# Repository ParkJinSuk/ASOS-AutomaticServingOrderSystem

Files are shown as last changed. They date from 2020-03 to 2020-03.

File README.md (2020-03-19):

# Project Name 

ASOS
Automatic Serving & Order System 

# Project period & team members

2020.02.21 ~ 2020.03.21 (4주) 
시립대 박진석, 서재원, 송태헌

# 요약 

본 프로젝트는 식당에서 사용할 수 있는 자동으로 서빙을 해주는 무인 서빙 로봇, 주문을 해주는 어플리케이션과 주문을 확인하고 서빙 명령이 가능한 웹페이지 제작을 한다. 서빙 로봇은 Wi-Fi와 연결되었기 때문에 공유기가 설치된 환경이면 어디서든 환경이 가능하고, 주문한 음식은 서버에 저장되기 때문에 완벽한 IoT를 구현하였다.   

# 개발 배경 

현대사회에서 생산성과 효율을 위해서 많은 분야에서 무인/자동화가 이루어지고 있다. 이러한 추세에 따라 매장에 무인 주문 결제기인 ‘키오스크’가 설치되고 있고, 일부 매장은 어플로 주문을 하는 시스템을 도입했다. 따라서 위의 주문 시스템에 자동으로 서빙을 로봇을 융합함으로 IoT를 이용한 무인 서비스 제공을 목표로 한다. 

# 프로젝트 목적 및 기대효과 

이 프로젝트의 목적은 주문/서빙 시스템의 자동화이다. 병렬적으로 주문을 할 수 있는 무인 주문서비스와 무인 서빙 서비스를 만드는 것이 목표이다. 무인 서빙 서비스가 있기 때문에 서빙에 필요한 인건비가 줄어들어 경제적이고 효율적이다. 무인 주문 서비스를 통해서 순간적으로 사람이 집중이 되더라도 주문하는데 기다릴 필요가 없게 된다. 또한, 주방에서 출력된 종이 영수증을 보통 주문의 순서를 정하는데, 이 프로젝트를 통해서 종이 영수증대신 태블릿 PC와 같은 전자기기로 대체할 수 있을 것이다. 이에 따라 주방에서 낭비되는 종이의 양을 줄여서 환경보호면에서도 효과가 있다. 또한, 보드는 Arduino UNO만을 사용하고 성능을 대부분 사용하여 개발을 했기 때문에 실제 제품으로 만들 시 제품 비용 절감이 매우 절감될 것이다.  

# MySQL 명령어 모음

Column 이름 변경
```
ALTER TABLE `project`.`orderDB` 
CHANGE COLUMN `order` `_order` INT(11) NOT NULL AUTO_INCREMENT ,
CHANGE COLUMN `table` `_table` INT(11) NOT NULL ;
```

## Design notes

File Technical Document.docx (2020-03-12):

# 2020 ICT 융합 프로젝트 공모전

# 1. 프로젝트 소개

## 1.1 프로젝트 명

Linetracer를 활용한 Restaurants Serving Robot

## 1.2 프로젝트 기간

2020.02.21 ~ 2020.03.21 (4주)

## 1.3 프로젝트 팀원

서울시립대학교 기계정보공학과 갓진석

서울시립대학교 기계정보공학과 서재원

서울시립대학교 기계정보공학과 송태헌

# 2. 프로젝트 개요

## 2.1 요약

라인트레이서 센서를 사용해서 식당에서 사람을 대신해서 음식을 서빙 해주는 로봇과 식당 테이블에서 QR 코드를 통해서 주문을 할 수 있는 무인 주문&서빙 시스템을 제작한다. 식당 이용객은 테이블 QR 코드를 찍음으로써 간단하게 주문을 하고 주문을 받는 주방에서는 로봇 위에 음식을 올려놓으면 자동으로 주문한 테이블로 배달이 되도록 한다.

## 2.2 개발 배경

현대사회에서 생산성과 효율을 위해서 많은 분야에서 무인화/자동화가 이루어지고 있다. 이러한 추세에 따라 매장에 무인 주문 결제기인 ‘키오스크’가 설치되고 있고, 일부 매장은 어플로 주문을 하는 시스템을 도입했다. 본 프로젝트에서는 위의 주문 시스템에 자동으로 서빙을 로봇을 융합함으로 IoT를 이용한 무인 서비스 제공을 목표로 한다.

## 2.3 프로젝트 목적 및 기대효과

이 프로젝트의 목적은 주문&서빙 시스템의 자동화 및 디지털화이다. 병렬적으로 주문을 할 수 있는 무인 주문서비스와 무인 서빙 서비스를 만드는 것이 목표이다. 무인 서빙 서비스가 있기 때문에 서빙에 필요한 인건비가 줄어들어 경제적이고 효율적이다. 무인 주문 서비스를 통해서 순간적으로 사람이 집중이 되더라도 주문하는데 기다릴 필요가 없게 된다. 또한, 주방에서 출력된 종이 영수증을 보통 주문의 순서를 정하는데, 이 프로젝트를 통해서 종이 영수증대신 태블릿 PC와 같은 전자기기로 대체할 수 있을 것이다. 이에 따라 주방에서 낭비되는 종이의 양을 줄여서 환경보호면에서도 효과가 있다.

## 2.4 개발 목표

많은 사람들이 집중되더라도 한꺼번에 처리가 가능한 무인 병렬 주문 서비스와 주방에서 서빙할 테이블의 번호를 지정해준다면 자동으로 서빙을 해주는 서비스 구현이 목표이다.

## 2.5 세부 개발 내용

네이버 클라우드에 비용을 지불해서 구축한 서버에 APM(Apache2, PHP, MySQL)을 설치하고, 웹 페이지와 안드로이드 어플을 제작하여 주문한 데이터가 DB인 MySQL에 저장되도록 한다. 관리자는 관리자용 웹페이지를 통해서 MySQL에 저장된 데이터를 확인해서 들어온 주문을 확인할 수 있다. 서빙을 원하는 테이블을 웹 페이지에 입력하면 마찬가지로 MySQL에 저장이 된다. 아두이노는 매장에 설치된 Wi-Fi와 연결된 상태로 구동되고, 일정 간격으로 MySQL을 확인해서 서빙 요청이 왔는지 확인한다. 서빙 명령을 받게 되면 목표 테이블까지 라인트레이싱을 하며 도달하게 된다. 이 때 서빙 하는 음식의 무게에 상관없고, 가속도에 의한 음식의 미끄러짐을 최소화하기 위해서 모터 PID속도 제어를 통해서 운동한다.

# 3. 프로젝트 설명

## 3.1 주요 동작 및 특징

QR코드를 통한 웹페이지 접근 -> 주문이 MySQL에 쌓임

주방에서 웹페이지를 실시간으로 확인이 가능 -> 서빙을 원하는 테이블 번호를 MySQL에 전송

Arduino에서 실시간으로 Wi-Fi를 통한 TCP 통신 -> MySQL에서 테이블 번호를 입력 받음 -> 해당 테이블로 이동

Arduino가 급격하게 움직이면서 관성으로 인한 음식 떨어뜨림, 안전하고 신속하게 이동할 수 있는 최적 속도를 계산해서 구동하도록 하는 모터 PID 제어

## 3.2 전체 시스템 구성

### 3.2.1. Software Architecture

#### 3.2.1.1. Server Flowchart

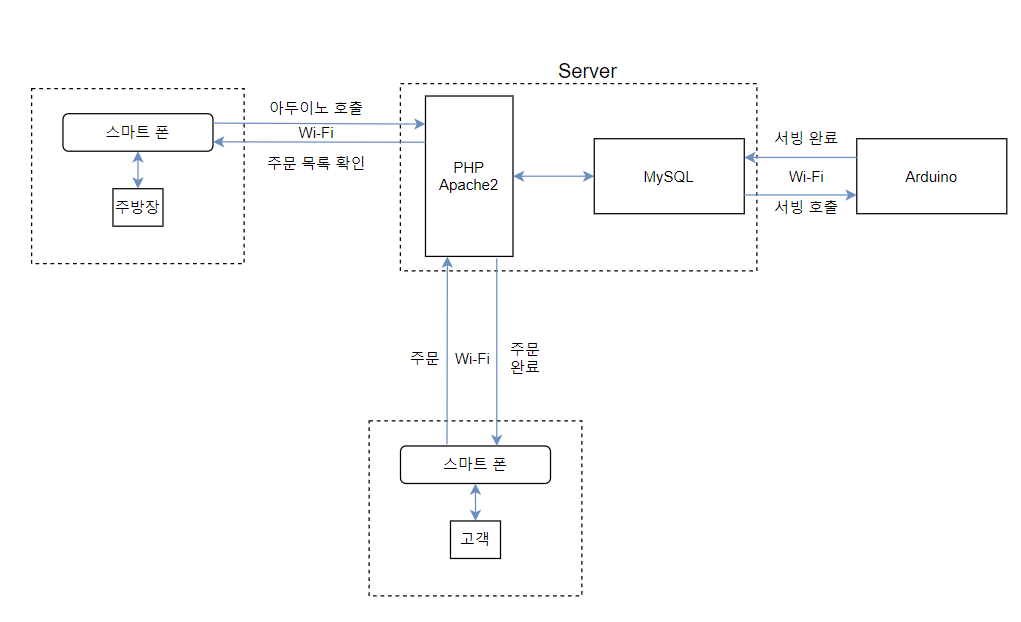
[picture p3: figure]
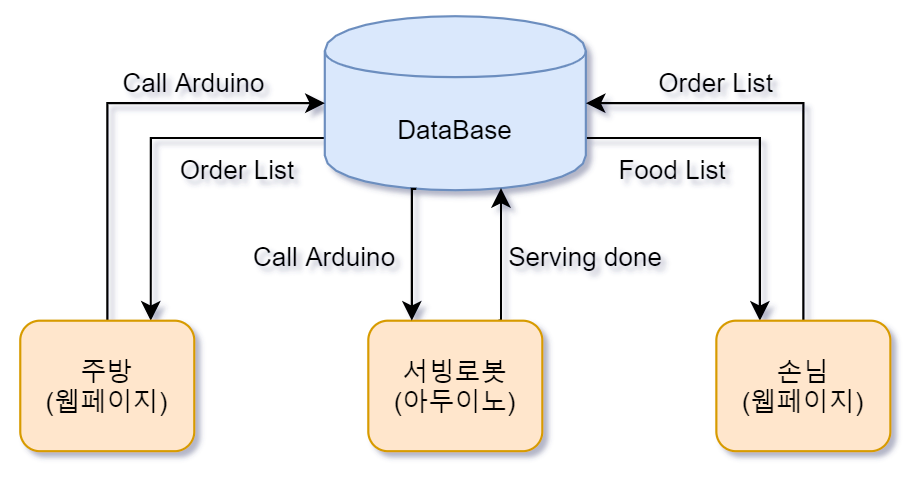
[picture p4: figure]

손님이 주문을 하고 RC카(아두이노)가 서빙을 하기 위한 방법으로 서버를 사용하였다. 손님이 주문을 하면 주문내역이 서버의 데이터베이스에 저장이 되고 주방에서는 서버의 데이터베이스를 확인하여 RC카(아두이노)를 호출한다. RC카(아두이노)에서는 서버의 데이터베이스를 통해서 호출 신호가 왔을 때, 지정된 테이블로 음식을 서빙한다.

3.2.2. Hardware Architecture

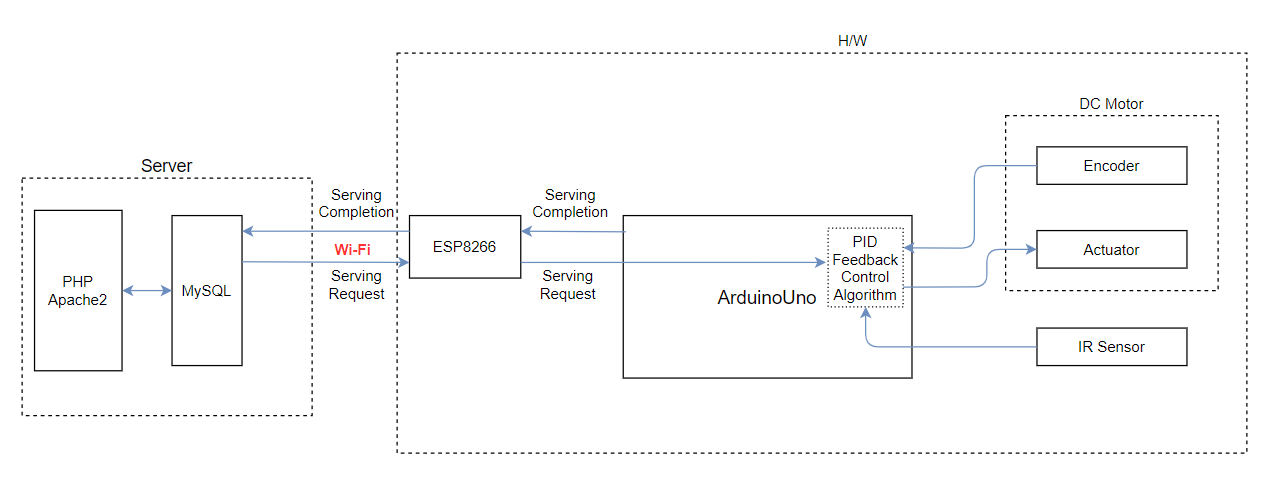
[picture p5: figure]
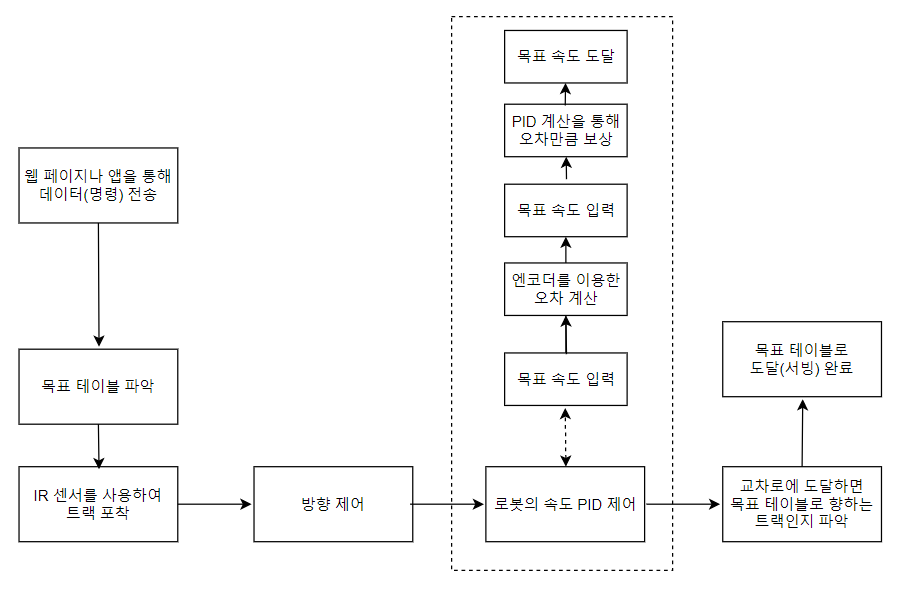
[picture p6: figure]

## 3.3 개발 환경(개발 언어, Tool, 사용 시스템 등)

구분 | | 내용
서버 구축 | 플랫폼 | 네이버 클라우드
| OS | Ubuntu 16.04 (Linux)
| Tool | Apache2/MySQL/PHP
| 개발 언어 | html/PHP/C/C++
H/W | 디바이스 | Arduino Uno/DC Motor W/ Encoder
| 센서 | HS-IR-TRACE-II
| Wi-Fi 통신 | ESP8266
| 개발 언어 | C/C++
| 기타 | MATLAB Simulink를 통한 DC모터의 PID 제어

# 4. 단계별 제작 과정

## 4.1. 서버구축

서버는 네이버 클라우스 서비스를 사용하여 구축하였다. 기본적으로 유료서비스이지만 작은 규모의 서버를 1년동안 무료로 사용할 수 있는 이벤트가 있어서 네이버 서버를 선택하였다. 서버의 사양은 [Micro] 1vCPU, 1GB Mem, 50GB Disk이라 성능은 좋지 않지만 이번 프로젝트에서는 문제가 없다고 판단하였다. 서버의 OS는 Ubuntu 16.04 LTS Server를 설치하였다.

## 4.2 APM 설치

(갓째원 적어줘요~)

## 4.3 MySQL 데이터베이스 구축

Windows에서 MySQL Workbench를 설치하여 좀 더 쉽게 MySQL를 다룰 수 있도록 하였다. orderDB의 테이블 속, 각 데이터들은 다음을 의미한다. _order는 주문순서, time는 주문시간, _table는 주문 테이블 번호, food는 주문한 음식과 수량, serving는 서빙이 완료되었는지 안되었는지, call_arduino는 RC카(아두이노)가 확인하는 데이터로써 값이 1일 경우, RC카(아두이노)가 음식을 서빙한다.

_order열에는 값을 입력하지 않아도 자동으로 값이 1씩 증가하도록 설정하였고, time은 ubuntu서버에 있는 시간을 자동으로 입력 받도록 설정하였다. 아래에 기술할 웹페이지에서 _table, food, call_arduino열을 설정할 수 있도록 연동하였다.

## 4.4 웹 페이지 제작

4.4.1 손님용 웹 페이지

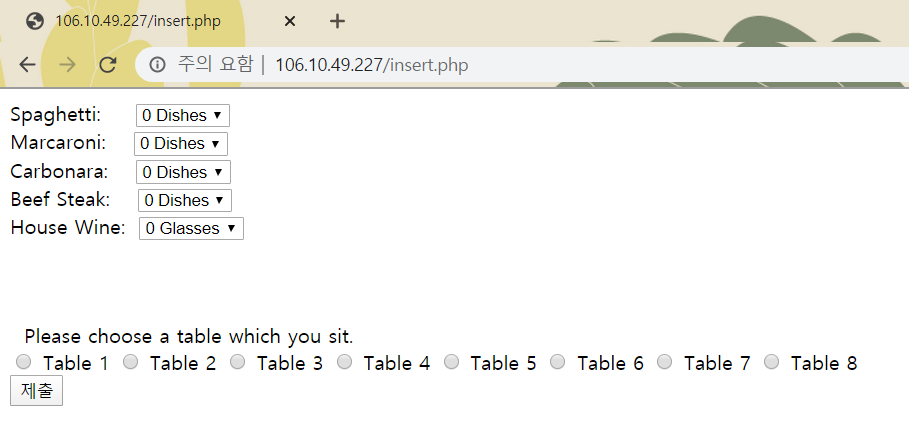
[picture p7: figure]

손님용 웹페이지

구축한 서버를 통해 웹 페이지를 제작했고, 포트 포워딩을 설정하여 외부 IP를 이용하여 접속이 가능하도록 하였다. 현재 제공하고 있는 음식의 목록과 개수를 HTML 리스트박스를 통해서 선택하고, 앉을 테이블 번호를 라디오 버튼을 이용해서 선택할 수 있다. ‘제출’버튼을 누르면 서버의 데이터베이스인 MySQL에 저장이 된다. insert.php에서는 웹 페이지에서 정보를 받아와서 MySQL에 데이터를 입력하는 코드를 구성하였고, dbcon.php에는 MySQL에 접근하는 코드를 구현하였다. 이 웹 페이지를 생성하기 위한 php파일의 코드는 아래와 같다.

insert.php 코드

<?php

error_reporting(E_ALL);

ini_set('display_errors',1);

include('dbcon.php');

if( ($_SERVER['REQUEST_METHOD'] == 'POST') && isset($_POST['submit']))

{

$_table=$_POST['_table'];

$food="Spaghetti: ".$_POST['amount_a']."<br>Macaroni: ".$_POST['amount_b']."<br>Carbonara: ".$_POST['amount_c']."<br>Beef Steak: ".$_POST['amount_d']."<br>House Wine: ".$_POST['amount_e'];

if(!isset($errMSG))

{

try{

$stmt = $con->prepare('INSERT INTO orderDB(_table, food) VALUES(:_table, :food)');

$stmt->bindParam(':_table', $_table);

$stmt->bindParam(':food', $food);

if($stmt->execute())

{

$errMSG = 'We just got your order. Thank you.';

}

else

{

$errMSG = "Unexpected error occured. Please try again.";

}

} catch(PDOException $e) {

die("Database error: " . $e->getMessage());

}

}

}

?>

<html>

<body>

<?php

if (isset($errMSG)) echo $errMSG;

if (isset($successMSG)) echo $successMSG;

?>

<form action="<?php $_PHP_SELF ?>" method="POST">

Spaghetti:&nbsp;&nbsp;&nbsp;&nbsp;

<select name="amount_a">

<option value="0"> 0 Dishes</option>

<option value="1"> 1 Dish</option>

<option value="2"> 2 Dishes</option>

<option value="3"> 3 Dishes</option>

<option value="4"> 4 Dishes</option>

</select>

<br>

Marcaroni:&nbsp;&nbsp;&nbsp;

<select name="amount_b">

<option value="0"> 0 Dishes</option>

<option value="1"> 1 Dish</option>

<option value="2"> 2 Dishes</option>

<option value="3"> 3 Dishes</option>

<option value="4"> 4 Dishes</option>

</select>

<br>

Carbonara:&nbsp;&nbsp;&nbsp;

<select name="amount_c">

<option value="0"> 0 Dishes</option>

<option value="1"> 1 Dish</option>

<option value="2"> 2 Dishes</option>

<option value="3"> 3 Dishes</option>

<option value="4"> 4 Dishes</option>

</select>

<br>

Beef Steak:&nbsp;&nbsp;&nbsp;

<select name="amount_d">

<option value="0"> 0 Dishes</option>

<option value="1"> 1 Dish</option>

<option value="2"> 2 Dishes</option>

<option value="3"> 3 Dishes</option>

<option value="4"> 4 Dishes</option>

</select>

<br>

House Wine:&nbsp;

<select name="amount_e">

<option value="0"> 0 Glasses</option>

<option value="1"> 1 Glass</option>

<option value="2"> 2 Glasses</option>

<option value="3"> 3 Glasses</option>

<option value="4"> 4 Glasses</option>

</select>

<br>

<form action="<?php $_PHP_SELF ?>" method="POST">

<br><br><br> &nbsp; Please choose a table which you sit. <br>

<input type = "radio" name = "_table" value = "1" /> Table 1

<input type = "radio" name = "_table" value = "2" /> Table 2

<input type = "radio" name = "_table" value = "3" /> Table 3

<input type = "radio" name = "_table" value = "4" /> Table 4

<input type = "radio" name = "_table" value = "5" /> Table 5

<input type = "radio" name = "_table" value = "6" /> Table 6

<input type = "radio" name = "_table" value = "7" /> Table 7

<input type = "radio" name = "_table" value = "8" /> Table 8 <br>

<input type = "submit" name = "submit" />

</form>

</body>

</html>

dbcon.php 코드

<?php

$host = 'localhost';

$username = '#########'; # MySQL 계정 아이디

$password = '#########'; # MySQL 계정 패스워드

$dbname = 'project'; # DATABASE 이름

$options = array(PDO::MYSQL_ATTR_INIT_COMMAND => 'SET NAMES utf8');

try {

$con = new PDO("mysql:host={$host};dbname={$dbname};charset=utf8",$username, $password);

} catch(PDOException $e) {

die("Failed to connect to the database: " . $e->getMessage());

}

$con->setAttribute(PDO::ATTR_ERRMODE, PDO::ERRMODE_EXCEPTION);

$con->setAttribute(PDO::ATTR_DEFAULT_FETCH_MODE, PDO::FETCH_ASSOC);

if(function_exists('get_magic_quotes_gpc') && get_magic_quotes_gpc()) {

function undo_magic_quotes_gpc(&$array) {

foreach($array as &$value) {

if(is_array($value)) {

undo_magic_quotes_gpc($value);

}

else {

$value = stripslashes($value);

}

}

}

undo_magic_quotes_gpc($_POST);

undo_magic_quotes_gpc($_GET);

undo_magic_quotes_gpc($_COOKIE);

}

header('Content-Type: text/html; charset=utf-8');

#session_start();

?>

4.4.2 관리자용 웹 페이지

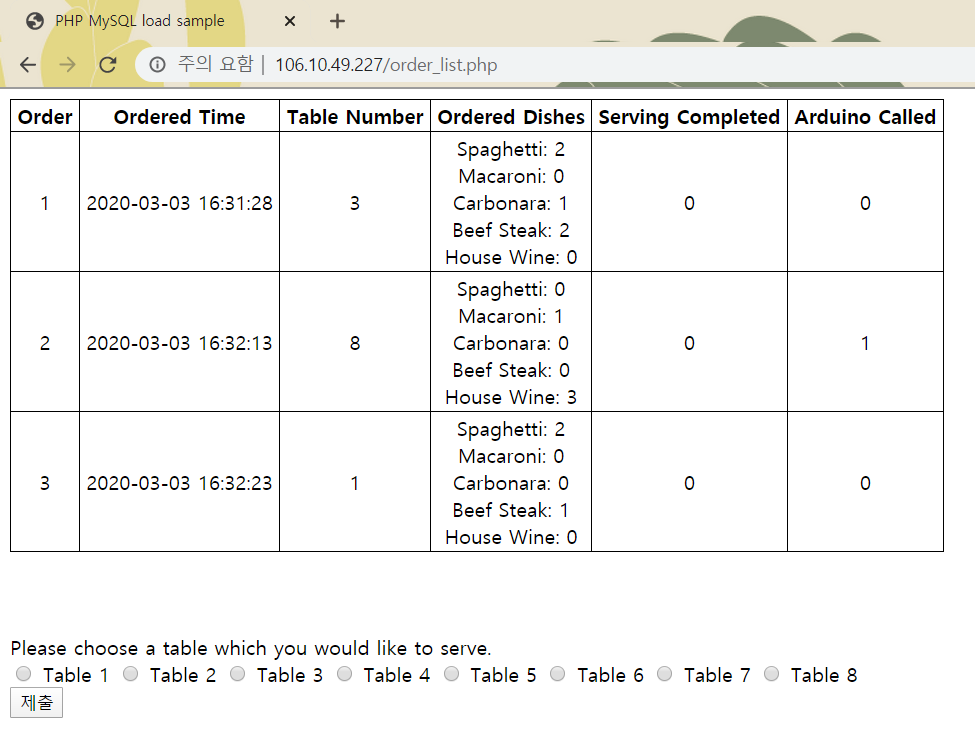
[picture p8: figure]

손님용 웹페이지에서 입력한 MySQL 정보를 읽어와서 표로 표현해주는 기능을 한다. 요리가 완료되면 아래에 있는 테이블 번호를 입력하고 ‘제출’버튼을 누르면 Arduino Called열이 1로 바뀌어 아두이노에게 서빙 명령을 내릴 수 있다. 위의 기능을 실행하기 위한 order_list.php의 코드는 아래와 같다.

<CTYPE html>

<html>

<head>

<meta charset="UTF-8" />

<title>PHP MySQL load sample</title>

<style type="text/css">

table {

border: 0;

border-collapse: collapse;

border-spacing: 0;

}

table td, table th {

border: 1px solid;

padding: 2px 5px 2px 5px;

}

.text-center { text-align: center; }

.text-right { text-align: right; }

</style>

</head>

<body>

<?php

/* Load DB */

$conn = mysqli_connect('localhost', '#######', '########', 'project'); #MySQL 아이디, 패스워드 입력

if ( !$conn ) die('DB Error');

/* Set to UTF-8 Encoding */

mysqli_query($conn, 'set session character_set_connection=utf8;');

mysqli_query($conn, 'set session character_set_results=utf8;');

mysqli_query($conn, 'set session character_set_client=utf8;');

/* Load data */

$query = 'SELECT * FROM orderDB';

$result = mysqli_query($conn, $query);

echo '<table class="text-center"><tr>' .

'<th>Order</th><th>Ordered Time</th><th>Table Number</th><th>Ordered Dishes</th><th>Serving Completed</th><th>Arduino Called</th>' .

'</tr>';

while( $row = mysqli_fetch_array($result) ) {

echo '<tr><td>' . $row['_order'] . '</td>' .

'<td>' . $row['time'] . '</td>' .

'<td>' . $row['_table']. '</td>' .

'<td>' . $row['food'] . '</td>' .

'<td>' . $row['serving']. '</td>' .

// '<td class="text-right">' .

'<td>' . $row['call_arduino'] . '</td></tr>';

}

echo '</table>';

//mysqli_close($conn);

?>

<form action="<?php $_PHP_SELF ?>" method="POST">

<br><br><br> Please choose a table which you would like to serve. <br>

<input type = "radio" name = "table_num" value = "1" /> Table 1

<input type = "radio" name = "table_num" value = "2" /> Table 2

<input type = "radio" name = "table_num" value = "3" /> Table 3

<input type = "radio" name = "table_num" value = "4" /> Table 4

<input type = "radio" name = "table_num" value = "5" /> Table 5

<input type = "radio" name = "table_num" value = "6" /> Table 6

<input type = "radio" name = "table_num" value = "7" /> Table 7

<input type = "radio" name = "table_num" value = "8" /> Table 8 <br>

<input type = "submit" name = "submit" />

</form>

<?php

$insertQuery = "update orderDB set call_arduino = 1 where _table = ".$_POST['table_num'];

mysqli_query($conn, $insertQuery);

?>

</body>

</html>

## 4.5 QR코드 생성

웹사이트 https://ko.qr-code-generator.com/ 에서 URL를 QR코드로 바꿔주는 서비스를 통해서 웹페이지 두개(관리자용, 손님용)를 QR코드로 바꾸어 주었다.

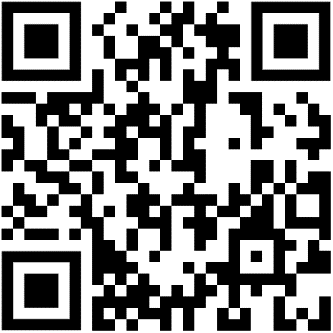
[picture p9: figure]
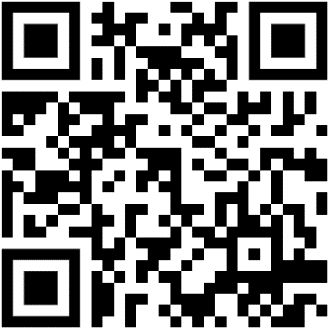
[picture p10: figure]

QR코드(관리자용) | QR코드(손님용)

## 4.6 Arduino에서 Wi-Fi통신을 통한 MySQL 데이터 수신

## 4.7 DC모터의 PID Feedback Control

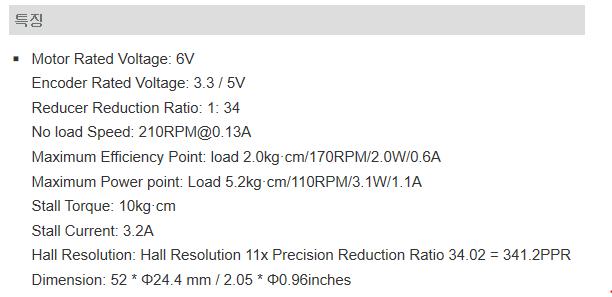
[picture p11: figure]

위의 모터의 Specification을 참고해서 [T:토크(kgf∙cm) V:전압(V), I:전류(A), w:각속도(rad/s), R:저항(Ω)] 아래의 관계식을 세울 수 있다.

T∝ (VI)/w

V=IR

두개의 식을 연립하고 비례상수 k를 도입하면 아래의 식으로 변환이 가능하다.

Tw=k (V^2)/R

Stall Torque는 최대 토크의 값을 의미하고, 이는 최대 전압인 6V와 Stall Current인 3.2A일 때 성립한다. 따라서 옴의 법칙에 의해서

6=3.2R

R=1.875Ω

모터의 저항은 1.875Ω이다.

또한, Maximum Power Point의 값을 Tw=k (V^2)/R 에 대입하면

5.2=k 3.1/11.5192

k=19.3225

비례상수 k값을 수 있다. 위의 식을 정리하면

Tw= V^2 k/R = V^2 19.3225/1.875 =10.3053 V^2

Tw=10.3053 V^2

# 의 식을 구할 수 있다. 아두이노에서 pwm제어로 V를 제어할 수 있기 때문에, V가 각각 1V, 2V, 3V, 4V, 5V, 6V일 때 x축을 각속도, y축을 토크로 그래프를 도사하면 아래와 같다.

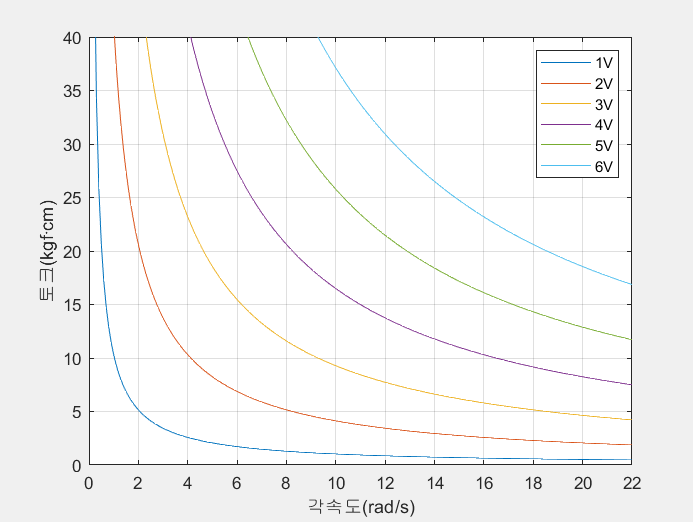
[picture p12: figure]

전압을 가했을 때 각속도와 토크의 값을 정확히 모델링으로부터 알 수 없기 때문에, 엔코더를 이용해서 측정한 각속도 각속도 값은 다음과 같다.

V | rad/s
2 | 4.5524
3 | 4.858997
4 | 7.366162
5 | 23.95988
6 | 24.6999

이 값을 바탕으로 토크 값을 추출하고, Line Fitting을 통해서 전압<->각속도, 전압<->토크의 관계를 알아낼 수 있다.

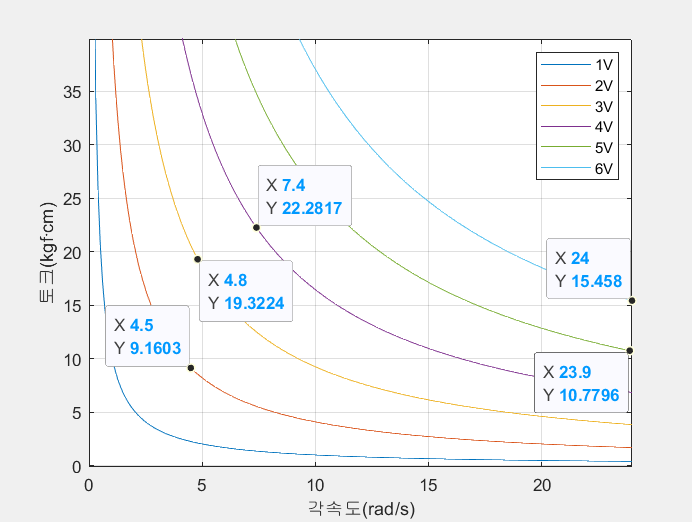
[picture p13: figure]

아마도 위의 데이터는 날려버랴아 할 듯 ㅠㅠㅠㅠㅠㅠ

또한, DC모터의 스펙으로부터 전류에 다른 토크의 값을 아래와 같이 기입할 수 있다.

V | rad/s
2 | 4.5524
3 | 4.858997
4 | 7.366162
5 | 23.95988
6 | 24.6999

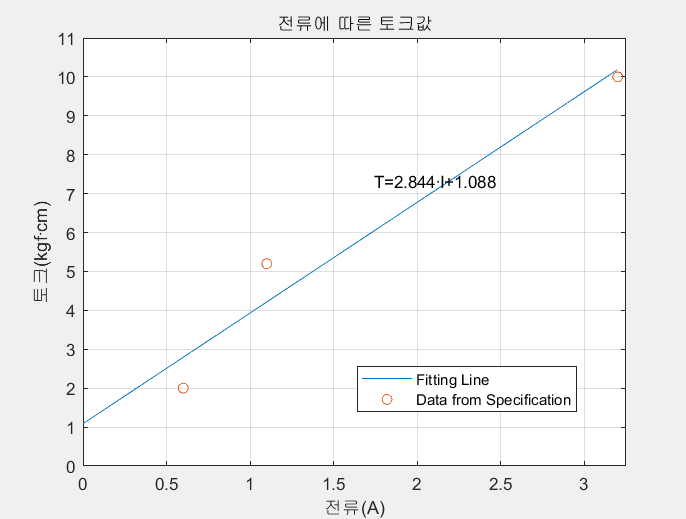
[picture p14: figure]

DC모터, 아두이노 차체 시스템에서 차체를 모델링하여 전달함수를 구하기 위하여 Free Body Diagram을 그려서 계산할 필요가 있다.

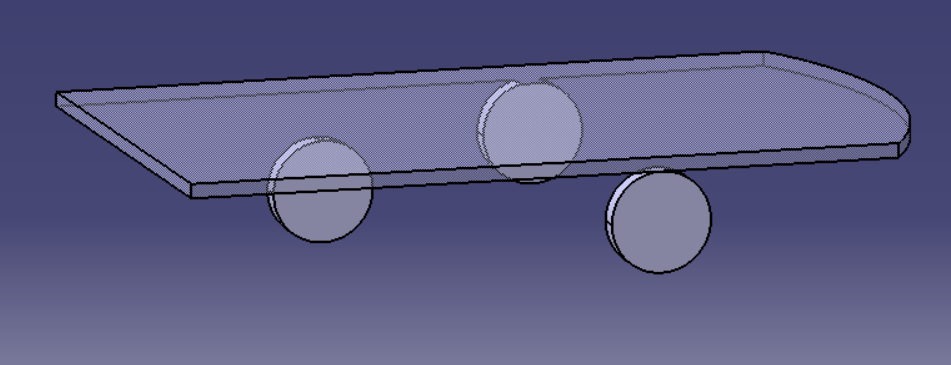
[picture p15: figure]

6.5cm

F

F

v

위의 그림에서 오른쪽에 있는 두개의 원이 모터가 달린 바퀴이고, 왼쪽에 있는 원은 캐스터이다. 바닥과의 마찰이 충분하여 바퀴가 헛도는 상황이 발생하지 않는다고 가정하면, 모터에 의한 토크는 바퀴 두개에 가해지는 힘으로 생각할 수 있다. 위의 그림을 다시 차체에 대해서만 Free Body Diagram을 그리면 아래와 같이 간단한 형태로 나타낼 수 있다.

cv

2F

모터에 의한 추진력 2F와 공기저항과 같은 저항에 의한 반력이 생기기 때문에 cv를 도입하였으나, 영향은 작을 것으로 예측되어 c=0.1인 낮은 값으로 가정하였다. 바퀴의 반지름이 3.25cm인것을 고려하여 운동방정식을 세우면 아래와 같다.

2F-cv=mv

2F=(2T)/3.25, c=0.1

(2T)/3.25=0.1v+mv

여기에서 mv 은 비선형이므로, 라플라스 변환을 하기 위하여 테일러 급수를 이용해 정상상태에서의 선형화한 값을 도출해낸다.

mv=m_s v_s +v_s (m-m_s )+m_s (v-v_s )

차체의 무게는 약 400g이고, 정상상태에서 가속도는 작은 것을 목표로 v_s =0.01cm/s²을 대입하여 이 식을 정리한다.

mv=0.004+0.01(m-0.4)+0.4(v-0.01)

(2T)/3.25=0.1v+mv=0.1v+0.004+0.01(m-0.4)+0.4(v-0.01)

Fitting Line에서 구한 T=2.844∙I+1.088을 대입하여 위의 식을 정리한다.

(2(2.844∙I+1.088))/3.25=0.1v+0.004+0.01(m-0.4)+0.4(v-0.01)

상수를 모두 없애기 위해서, 이 식을 편차변수로 나타낼 수 있다.

(2(2.844∙I'))/3.25=0.1v'+0.01m'+0.4v'

옴의 법칙을 이용해서 전류를 전압에 대한 식으로 바꾼다.

(2(2.844∙I'))/3.25=(2(2.844∙V'))/(3.25∙1.875)=0.1v'+0.01m'+0.4v'

위 식을 라플라스 변환하면 다음과 같이 표현할 수 있다.

(2(2.844∙V'))/(3.25∙1.875)=0.1v'+0.01m'+0.4v'

0.9334V(s)=(0.4s+0.1)v(s)+0.01m(s)

이 전달함수를 구할 수 있다.

(v(s))/(V(s))=0.9334/(0.4s+0.1) (v(s))/(m(s))=(-0.01)/(0.4s+0.1)

이 식을 바탕으로 MATLAB을 활용하여 Simulink를 구성하면 다음과 같다.

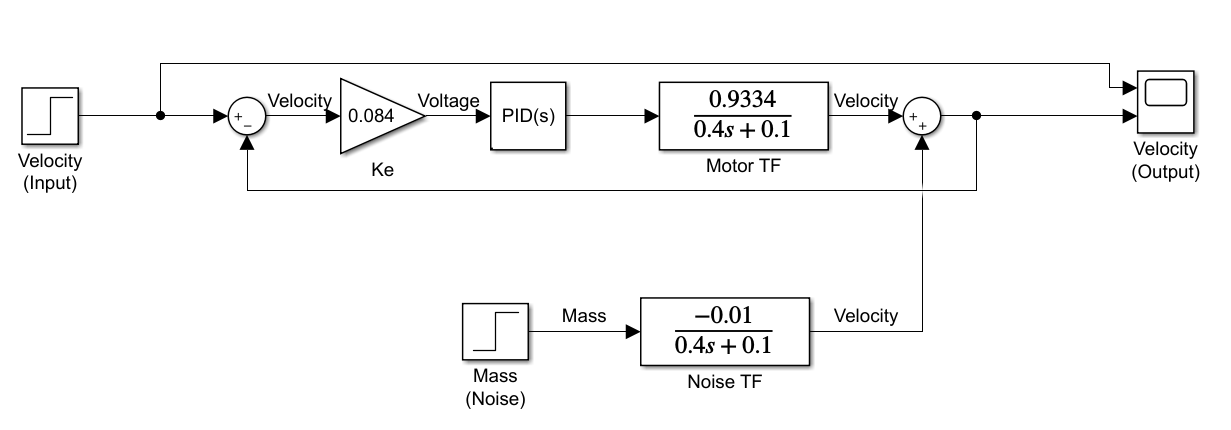
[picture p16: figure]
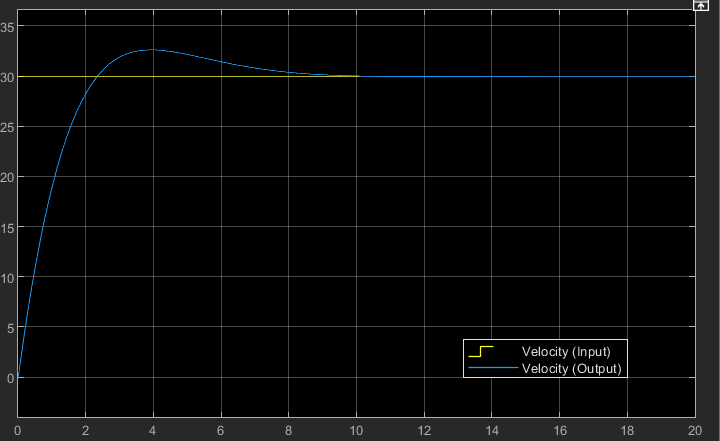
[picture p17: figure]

# 5. 기타(회로도, 소스코드, 참고문헌 등)

기타는 이렇다!

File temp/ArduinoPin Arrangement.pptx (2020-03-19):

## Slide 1

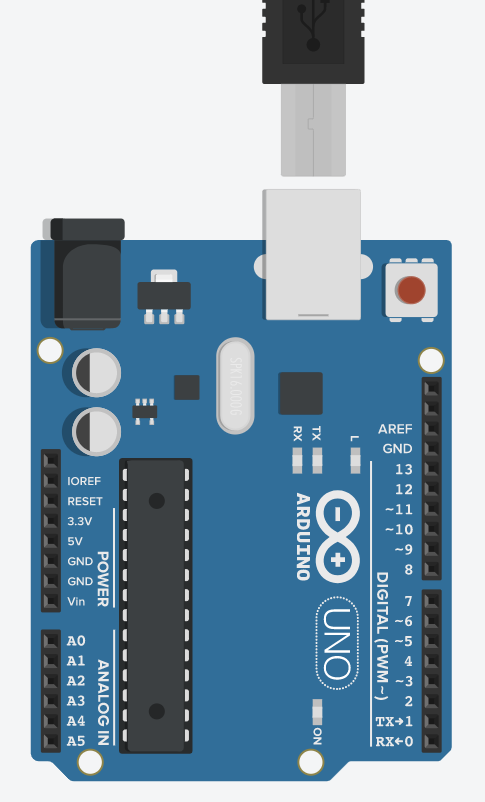
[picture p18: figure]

Motor_B Control2

Motor_B Control1

ESP-01 Adapter Rx

ESP-01 Adapter Tx

IR Sensor LeftOut

Motor_A Control2

Motor_A Control1

IR Sensor LeftIn

IR Sensor RightIn

Motor Encoder2

IR Sensor RightOut

Motor Encoder1

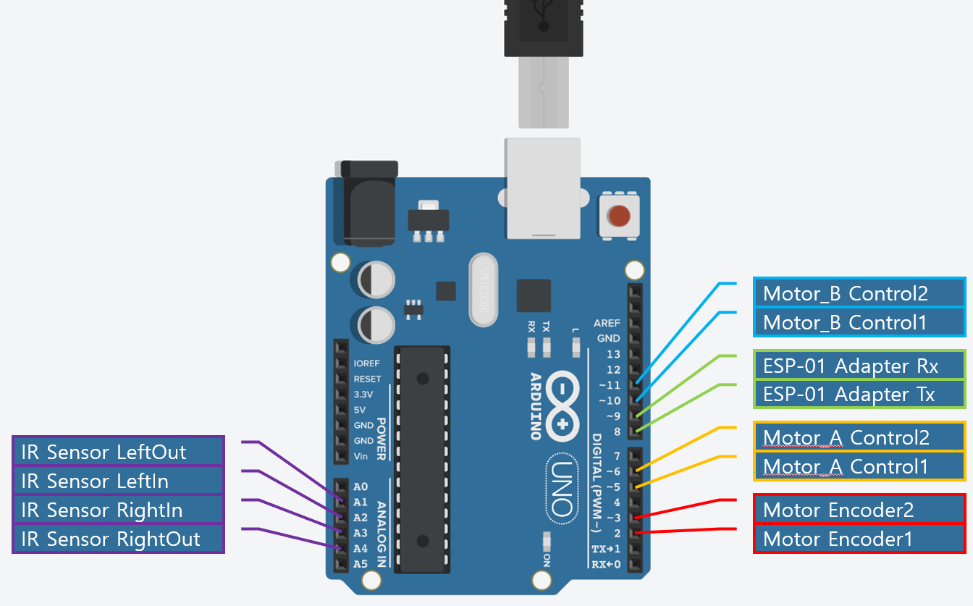
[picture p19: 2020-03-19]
temp/ArduinoPin Arrangement.PNG

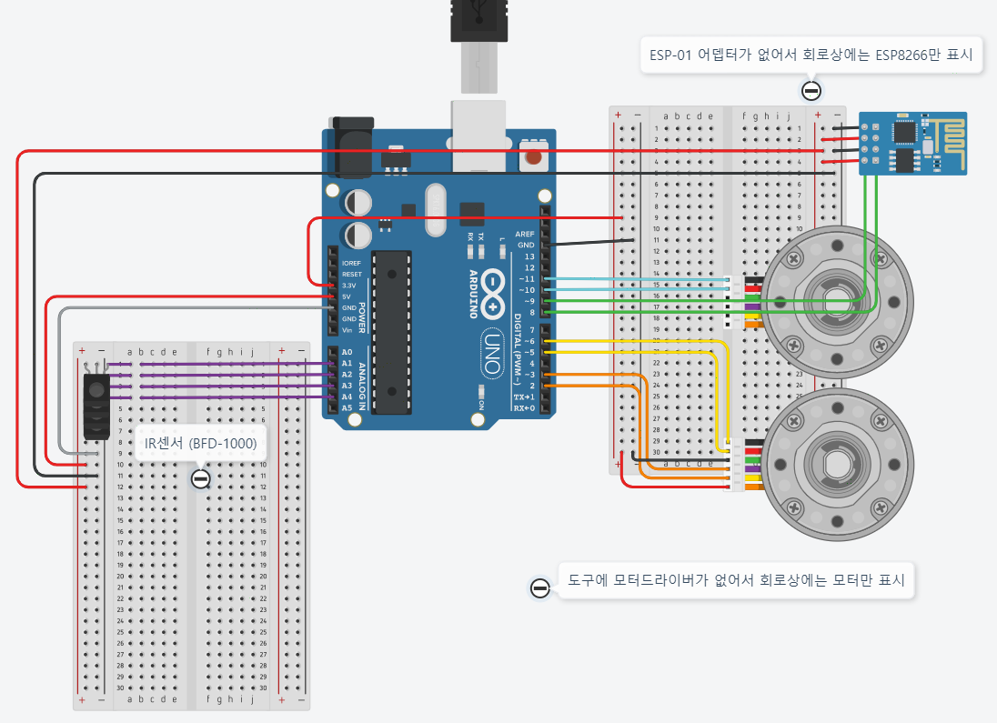
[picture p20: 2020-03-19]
temp/Arduino Circuit.PNG

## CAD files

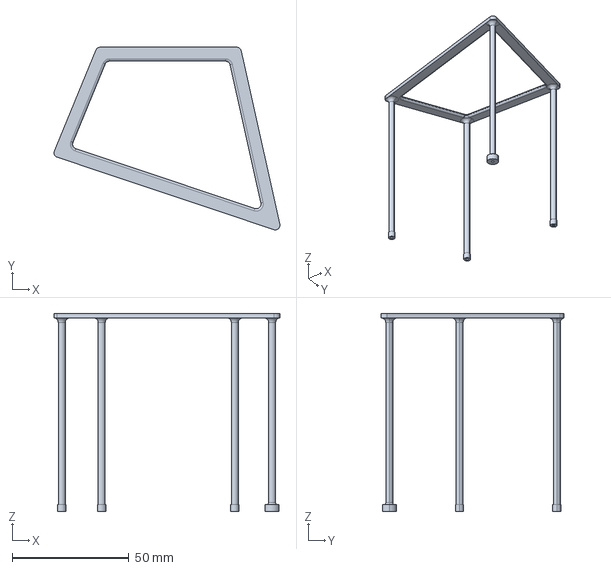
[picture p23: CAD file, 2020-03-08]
Frame/3D_print.igs
96.8 x 78.3 x 85.0 mm

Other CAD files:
Feedback Control/FBD.CATPart
Frame/3D_print.CATPart
Frame/3D_print.stl

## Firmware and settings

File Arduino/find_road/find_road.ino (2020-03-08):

/* 프로그램 내용 : 라인트레이서 모듈을 이용하여 길을 찾는 알고리즘
 * 
 * 라인트레이서 모듈에는 5개의 IR 센서가 존재하는데 그중에서
 * 가운데의 3개는 직선 길을 찾는데 사용하고
 * 가장자리 2개는 커브길의 존재를 탐지하는데 사용
 * 
 * 식당 내부의 길이 road.png 라고 가정할 때,
 * n번 테이블 : 직진 - 좌회전 - 직진 - (n번째 우회전 길에서 )우회전 - 직진
 * 
 * 
 * 프로그램 작성 날짜 : 2020년 2월 27일
 * 
 */


/* 핀번호 설정 */
#define SS1_LEFT_OUT  2
#define SS2_LEFT_IN   4
#define SS3_CENTER    7
#define CLP_BUMP      8
#define SS4_RIGHT_IN  11
#define SS5_RIGHT_OUT 12
#define NEAR          A5

#define MotorA1       3
#define MotorA2       5
#define MotorB1       6
#define MotorB2       9

/* 서빙로봇 */
int Stop      = 0;
int Left      = 1;
int Straight  = 2;
int Right     = 3;
int Back      = 4;

int   route[]= {Stop, Stop, Stop, Stop, Stop};  // 서빙로봇의 경로를 저장
int   stack_right;  // 우회전길이 보일때마다 하나씩 증가
int   cmd;         // 서빙로봇이 나아갈 방향
int   route_target[] = {Straight, Left, Straight, Right, Straight};

/* 전역 변수 */
byte  LeftOut;
byte  LeftIn;
byte  Center;
byte  RightIn;
byte  RightOut;
byte  Bump;
int   Near;

int   target_table;

unsigned long time; // 시간 측정을 위한 변수
int           temp;
unsigned long RightTime;

void setup() {
  pinMode(MotorA1, OUTPUT);
  pinMode(MotorA2, OUTPUT);
  pinMode(MotorB1, OUTPUT);
  pinMode(MotorB2, OUTPUT);
  
  Serial.begin(9600);
  Serial.println("###### Setup #####");

  time = millis();

}

void loop() {
  target_table = 1;

  cmd = Straight;
  
  /* 0.5초마다 라인트레이서 모듈 센서 측정 */
  if((millis() - time)%100 == 0)
  {
    getIRSensor();
    //showIRSensor();
  }

  //serving_table(target_table);

  /* 0.5초마다 주행 명령 */
  if((millis() - time)%100 == 0)
  {
    if (cmd == Straight)
    {
      forward();
    }
    
    if (cmd == Left)
    {
      //서빙로봇 좌회전
    }
    
    if (cmd == Right)
    {
      //서빙로봇 우회전
    }
    
    if (cmd == Stop)
    {
      //서빙로봇 정지
    }
  }
  

}




/* 라인트레이서 모듈 값 읽어오기 */
void getIRSensor()
{
  LeftOut  = digitalRead(SS1_LEFT_OUT);
  LeftIn   = digitalRead(SS2_LEFT_IN);
  Center   = digitalRead(SS3_CENTER);
  RightIn  = digitalRead(SS4_RIGHT_IN);
  RightOut = digitalRead(SS5_RIGHT_OUT);
  Bump     = digitalRead(CLP_BUMP);
  Near     = digitalRead(NEAR);
}
/* 라인트레이서 모듈 값 출력 */
void showIRSensor()
{
  if (LeftOut  == 1) {Serial.print("L ");} else {Serial.print("- ");}
  if (LeftIn   == 1) {Serial.print("l ");} else {Serial.print("- ");}
  if (Center   == 1) {Serial.print("C ");} else {Serial.print("- ");}
  if (RightIn  == 1) {Serial.print("r ");} else {Serial.print("- ");}
  if (RightOut == 1) {Serial.print("R ");} else {Serial.print("- ");}
  if (Bump     == 1) {Serial.print(" BUMP!");} else {Serial.print("      ");}
  if (Near     == 1) {Serial.print(" NEAR");}  else {Serial.print("    ");}
  Serial.println();
}
/********************************/




/* 서빙할 테이블로 찾아가는 알고리즘 */
void serving_table(int table_number)
{
  if (route[0] == Stop)
  {
    cmd = route_target[0]; // 서빙로봇의 방향 결정
    route[0] == route_target[0];
  }
  else if ((route[1] == Stop)  && (LeftOut == true))
  {
    cmd = route_target[1];
    route[1] == route_target[1];
  }
  else if ((route[2] == Stop)  && (LeftOut == false))
  {
    cmd = route_target[2];
    route[2] == route_target[2];
    
    temp = 0;
  }
  else if (route[3] == Stop)
  {
    if ((temp == 0) && RightOut == true)
    {
      RightTime = millis();
      temp = 1;
    }

    if (RightOut == false)
    {
      temp = 0;
    }
    
    if (((RightTime - millis()) > 100) && ((RightTime - millis()) < 1000))
    {
      stack_right += 1;
      temp = 0;
    }
  }
  else if ((route[3] == Stop)  && stack_right == table_number)
  {
    cmd = route_target[3];
    route[3] == route_target[3];
  }
  else if ((route[4] == Stop)  && RightOut == false)
  {
    cmd = route_target[4];
    route[4] == route_target[4];
  }

}
/*************************************/



/* 라인트레이서 모듈을 사용하여 검은색 선을 따라가는 함수 */
void forward()
{
  /*
  if (!LeftIn && !Center && !RightIn)
  {
    Serial.println("forward 111");
    MotorA(Straight, 230);
    MotorB(Straight, 230);
  }
  else if (LeftIn && !Center && !RightIn)
  {
    Serial.println("forward 011");
    MotorA(Straight, 150);
    MotorB(Straight, 210);
  }
  else if (!LeftIn && !Center && RightIn)
  {
    Serial.println("forward 110");
    MotorA(Straight, 210);
    MotorB(Straight, 150);
  }
  else if (LeftIn && Center && RightIn)
  {
    Serial.println("forward 000");
    MotorA(Stop, 0);
    MotorB(Stop, 0);
  }
  else
  {
    Serial.println("forward xxx");
    MotorA(Straight, 200);
    MotorB(Straight, 200);
  }
  */

  if (!LeftIn && !RightIn)
  {
    Serial.println("forward 111");
    MotorA(Straight, 170);
    MotorB(Straight, 170);
  }
  else if (LeftIn && !RightIn)
  {
    Serial.println("forward 011");
    MotorA(Straight, 150);
    MotorB(Straight, 80);
  }
  else if (!LeftIn && RightIn)
  {
    Serial.println("forward 110");
    MotorA(Straight, 80);
    MotorB(Straight, 150);
  }
  else if (LeftIn && RightIn)
  {
    Serial.println("forward 000");
    MotorA(Stop, 0);
    MotorB(Stop, 0);
  }
  else
  {
    Serial.println("forward xxx");
    MotorA(Straight, 200);
    MotorB(Straight, 200);
  }
  
  
}
void backward()
{
  Serial.println("backward");
}
void turnLeft()
{
  Serial.println("turn left");
}
void turnRight()
{
  Serial.println("turn right");
}
void _stop()
{
  Serial.println("stop");

  MotorA(Stop, 0);
  MotorB(Stop, 0);
}
/****************************/



/* 모터를 직접 컨트롤 하는 함수 */
void MotorA(int dir, int _speed)
{
  if (dir == Straight)
  {
    analogWrite(MotorA1, 0);
    analogWrite(MotorA2, _speed);
  }
  else
  {
    analogWrite(MotorA1, _speed);
    analogWrite(MotorA2, 0);
  }
}
void MotorB(int dir, int _speed)
{
  if (dir == Straight)
  {
    analogWrite(MotorB1, _speed);
    analogWrite(MotorB2, 0);
  }
  else
  {
    analogWrite(MotorB1, 0);
    analogWrite(MotorB2, _speed);
  }
}
/*****************************/

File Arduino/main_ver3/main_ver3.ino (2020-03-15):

#include "WiFiEsp.h"
#include <MySQL_Connection.h>
#include <MySQL_Cursor.h>
#include "SoftwareSerial.h"

  /* Arduino Pin */
#define SS1_LEFT_OUT  A1
#define SS2_LEFT_IN   A2
#define SS4_RIGHT_IN  A3
#define SS5_RIGHT_OUT A4

#define encoderPinA   2
#define encoderPinB   3

#define MotorA1       5
#define MotorA2       6
#define MotorB1       10
#define MotorB2       11




#define TURN_SPEED  200
#define STRAIGHT_SPEED  110

#define STRAIGHT_SPEED_STRONG  200
#define STRAIGHT_SPEED_WEEK  110

#define SENSING_PERIOD  100

/* global variable - IR sensor */
byte  LeftOut;
byte  LeftIn;
byte  RightIn;
byte  RightOut;

/* global variable - ServingRobot Direction */
int cmd_direction = 0;
int cnt_isRoad = 0;

/* 서빙로봇 명령 */
const int STOP      = 0;
const int LEFT      = 1;
const int STRAIGHT  = 2;
const int RIGHT     = 3;
const int BACK      = 4;
const int FORWARD_THROUGH_CROSSWALK = 5;


/* global variable - PID Control */
long encoderPos = 0;
double angle = 0, angle_pre=0;
int time1 = 0;
int value = 0;

double v;
double v_pre = 0;


float Kp = 4.2227;
float Ki = 2.29743;
float Kd = -0.03976;
float Ke = 0.084;

/*
float Kp = 1.674;
float Ki = 0.8239;
float Kd = -0.3584;
float Ke = 0.084;
*/
int k = 0;

double PControl, IControl=0, DControl, PIDControl;
double error, error_pre;
int pwm_in;

/* global variable - WiFi */
long target_table = 0;

/* global variable - Find Table */
int crosswalk[9] = {0, 1, 1, 2, 2, 3, 3, 4, 4};//갈림길 지나야하는 횟수. index 0은 사용하지 않는다.
int turn[9] = {0, LEFT, RIGHT, LEFT, RIGHT, LEFT, RIGHT, LEFT, RIGHT};//회전해야할 때, left로 가야하는지 right로 가야하는지
int crosswalkCnt = 0;//몇 번째 갈림길을 만났는지 체크!
bool isDone = true;

WiFiEspClient client;
MySQL_Connection conn((Client *)&client);
// Create an instance of the cursor passing in the connection
MySQL_Cursor cur = MySQL_Cursor(&conn);
MySQL_Cursor *cur_mem = new MySQL_Cursor(&conn);

SoftwareSerial esp(8, 9); // RX, TX


byte mac_addr[] = { 0xDE, 0xAD, 0xBE, 0xEF, 0xFE, 0xED };

IPAddress server_addr(106,10,49,227);  // IP of the MySQL *server* here
char user[] = "sexymandoo";              // MySQL user login username
char password[] = "sexymandoo";        // MySQL user login password

char ssid[] = "Sexy_Jaewon";             // 공유기 이름 SSID
char pass[] = "jaewonsexy";        // 공유기 암호 Password


// Sample query
char query[] = "SELECT _table FROM project.orderDB WHERE call_arduino = '1' AND serving = '0' ;";
char query2[] = "UPDATE project.orderDB SET serving = '1' WHERE call_arduino = '1' AND serving = '0' ;";


int status = WL_IDLE_STATUS;        // Status






int Hz = 20;
unsigned long time; // 시간 측정을 위한 변수


void setup() {
  pinMode(encoderPinA, INPUT_PULLUP);
  attachInterrupt(0, doEncoderA, CHANGE);
  pinMode(encoderPinB, INPUT_PULLUP);
  attachInterrupt(1, doEncoderB, CHANGE);

  pinMode(MotorA1, OUTPUT);
  pinMode(MotorA2, OUTPUT);
  pinMode(MotorB1, OUTPUT);
  pinMode(MotorB2, OUTPUT);
  
  Serial.begin(9600);
  esp.begin(9600);
  time = millis();

  WiFi.init(&esp);

    if (WiFi.status() == WL_NO_SHIELD)
  {
    Serial.println(F("WiFi shield not present"));
    while (true);
  }

  // 와이파이 접속여부 확인
  while (WiFi.status() != WL_CONNECTED)
  {
    Serial.print(F("Attempting to connect to WPA SSID: "));
    Serial.println(ssid);

    status = WiFi.begin(ssid, pass);
  }

  // 와이파이 접속정보
  Serial.println(F("You're connected to the network"));
  Serial.print(F("SSID: "));
  Serial.println(WiFi.SSID());

  IPAddress ip = WiFi.localIP();
  Serial.print(F("IP Address: "));
  Serial.println(ip);

  long rssi = WiFi.RSSI();
 
  Serial.println(F("Connecting to the server"));


  if (conn.connect(server_addr, 3306, user, password)) {
    delay(1000);
    Serial.println(F("Connected to the server"));
  }
  else
    Serial.println(F("Server connection failed."));


}

void loop() {
  
  if(target_table == 0){
    get_table_number();
    isDone = false;
    crosswalkCnt = 0; 
  }
  if(target_table != 0)
  {
    lineTracing();
  }
  if(isDone && (target_table != 0))
  {
    cur_mem->execute(query2); //MySQL에 서빙 완료를 알림
    cur.close();
    target_table = 0;
  }
  
  


  
  //pidControl_Hz(Hz, 30); // 30cm/s 속도로 주행
}

void get_table_number()
{
  row_values *row = NULL;
  target_table = 0;

  delay(1000);

  
 
  cur_mem = new MySQL_Cursor(&conn);
  // query를 실행시켜서 MySQL에서 데이터를 읽어옴
  cur_mem->execute(query);
  column_names *columns = cur_mem->get_columns();

  do {
    row = cur_mem->get_next_row();
    if (row != NULL) {
      
      target_table = atol(row->values[0]);
    }
  } while (row != NULL);
  // 동적 메모리 할당 지우기
  delete cur_mem;

  // 결과 출력
  Serial.print(F(" 서빙테이블 = "));
  Serial.println(target_table);

  delay(500);
}

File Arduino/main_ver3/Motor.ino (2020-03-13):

/*  프로그램 내용 : DC Motor 컨트롤하는 함수들
 *  
 *  MotorA              MotorA를 PWM 전압으로 조절하는 함수 
 *  MotorB              MotorB를 PWM 전압으로 조절하는 함수
 *  
 *  doEncoderA          DC모터 엔코더 카운트 하기 위한 함수
 *  doEncoderB          DC모터 엔코더 카운트 하기 위한 함수
 *  pos2ang             엔코더로부터 회전 각도 구하는 함수
 *  pos2ang_Hz          주어진 Hz속도로 회전 각도 구하는 함수
 *  
 */

void MotorA(int dir, int _speed)
{
  if (dir == STRAIGHT)
  {
    analogWrite(MotorA1, 0);
    analogWrite(MotorA2, _speed);
  }
  else
  {
    analogWrite(MotorA1, 0);
    analogWrite(MotorA2, 0);
  }
}

void MotorB(int dir, int _speed)
{
  if (dir == STRAIGHT)
  {
    analogWrite(MotorB1, _speed);
    analogWrite(MotorB2, 0);
  }
  else
  {
    analogWrite(MotorB1, 0);
    analogWrite(MotorB2, 0);
  }
}

void doEncoderA()
{
  encoderPos += (digitalRead(encoderPinA)==digitalRead(encoderPinB))?1:-1;
}

void doEncoderB()
{
  encoderPos += (digitalRead(encoderPinA)==digitalRead(encoderPinB))?-1:1;
}

void pos2ang()
{
  angle = -encoderPos/(341.2*4) * 360 /180*3.141592  ;
}

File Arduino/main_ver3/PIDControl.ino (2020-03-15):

void pidControl_Hz(int Hz, double input_v)
{
  double t = 0.1;
  pos2ang(); // 회전 각도 측정(라디안)
  v = 3.15*(angle-angle_pre)/t;
  angle_pre = angle;

  
  error=(input_v-v)*Ke;
  PControl=Kp*error;
  if(IControl <= 4){IControl+=Ki*error*t;} //Windup 방지
  //IControl+=Ki*error*t;
  DControl=Kd*(error-error_pre)/t;

  PIDControl=PControl+IControl+DControl;
  
  pwm_in=255/6*PIDControl;
  if(pwm_in>=255){pwm_in=255;}
  else if(pwm_in<=60){pwm_in=60;}
  
  
  Serial.print("pwm_in: "); Serial.print(pwm_in);
  Serial.print(" v:"); Serial.print(v);
  Serial.print(" error:"); Serial.print(error/Ke);
  Serial.print(" PIDControl: "); Serial.print(PIDControl);
  Serial.print(" P:"); Serial.print(PControl);
  Serial.print(" I:"); Serial.print(IControl);
  Serial.print(" D:"); Serial.println(DControl);
  
  
  //Serial.println(v);

  MotorA(STRAIGHT, pwm_in);
  MotorB(STRAIGHT, pwm_in);
  //MotorA(STRAIGHT, -50);
  //MotorB(STRAIGHT, -50);
  
  //angle_pre = angle;
  v_pre     = v;
  error_pre = error;
}

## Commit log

2020-02-15 wifi_test_with_esp01
    esp01에서 자체적으로 와이파이를 만들고, 핸드폰이 그 와이파이에 연결해서 스마트폰이 아두이노에 텍스트 전송해보리는 코드~
2020-02-16 Create 2020ICT 융합 프로젝트 공모전 안내.pdf
2020-02-20 Create test1.ino
    ESP8266, 아두이노 우노 사용.
    기상청에 HTML Request를 통해서
    응답을 받아내고
    이 응답을 parsing을 통해서 원하는 데이터(날씨)로 정제하고 출력하는 코드
    무슨이유인지 HTML 404 Not Found 오류가 발생함 ㅠㅠ
    아무튼 이 코드를 수정해서
    mysql의 데이터를 받아오고
    해당 데이터에 의해서 원하는 동작을 하도록 작동시킬 수 있을듯!
    [test1.ino]
2020-02-24 modified technical document
    [JustDoIt.xlsx]
2020-02-26 Create Volt, RPM, Torque.m
    간단한 전압, rpm, 토크의 관계 ㅎㅅㅎ
2020-02-27 pwm, torque, rpm
    pwm에 따른 토크, rpm값~~~
    내일은 모델링해서 실제 값이 잘 나오는지 조져보겠수다~
2020-02-29 컨트롤해버려
    [아두이노 속력 값.xlsx]
2020-03-03 기술문서로 가버려~
2020-03-03 모터 제어
2020-03-03 기술문서~
2020-03-03 기술문서어어어어어어
2020-03-03 기술문서, PID제어 시뮬링크 등등등...
2020-03-04 PID 계수 최종
    [FBD.CATPart]
2020-03-08 피드백 성공~~~~
2020-03-08 피드백
    속도 함수로 변환해 주세욤
2020-03-08 3D 프린터 모델링
    [3D_print.CATPart, 3D_print.igs, 3D_print.stl]
2020-03-12 기술문서
    ㅇㅅㅇ
2020-03-12 mysql 와이파이
2020-03-12 test1이 와이파이 mysql 연결 최종!
2020-03-12 find_road수정
2020-03-13 트랙주행 성공
2020-03-15 최종 코드
2020-03-15 기술문서
2020-03-15 app 부분 추가
2020-03-19 Create Technical Document_거의 최종.docx
2020-03-23 Update Technical Document_거의 최종.docx
